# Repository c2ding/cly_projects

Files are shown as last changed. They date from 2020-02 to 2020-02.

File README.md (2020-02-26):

# 项目说明

## 结构组成
>该项目涵盖以下几个子项目：**A_CARD**、**A_Box**、**B_Card**、**C_Slot**、**Dog**。
>
>
>
>| 序号 |     名称     |       备注       |
>| :--: | :----------: | :--------------: |
>|  1   | ***A_Card*** |       卡式       |
>|  2   | ***A_Box***  | 铝制型材外壳项目 |
>|  3   | ***B_Card*** |  大尺寸电路板卡  |
>|  4   | ***C_Slot*** |  7个插槽的项目   |
>|  5   |  ***Dog***   |    看门狗项目    |

## 说明
> 1. 当前 ***仓库***  只含有 ***Dog*** 看门狗项目的PCB设计文档、说明文档等内容，最早版本是2020-01-13，今天加入了看门狗用STM32芯片的刷写方法。2020-02-26
>
> 2. 刷写器的连接方式
>
> | 线序 | 板卡上     | 白色刷写器 |          |
> | ---- | ---------- | ---------- | -------- |
> | 标识 | 七针接口   | 四针接口   | 五针接口 |
> | 1    | NET_JTMS_1 | NULL       | RST      |
> | 2    | PA9        | NULL       | NULL     |
> | 3    | PA10       | NULL       | NULL     |
> | 4    | JTMS_SWDIO | SWIO       | SWIO     |
> | 5    | GND        | GND        | GND      |
> | 6    | VCC_3.3V   | 3.3V       | 3.3V     |
> | 7    | JTMS_SWCLK | CLK        | CLK      |
>
> 3. 看门狗工作命令
>
>    ~~~c
>    "StartOn" 		//激活看门狗功能；
>    "Hearbeat" 		//心跳功能，喂狗功能；
>    "StartOff"		//关闭看门狗功能；
>    "“SW_time"		//开关间隔参数设置；
>    "HB_time"		//心跳间隔参数设置。
>    
>    ~~~
>
>    ### 增加了如何使用Keil uVision编译并刷写固件

> 1. 当前 ***仓库***  只含有 ***Dog*** 看门购项目的PCB设计文档、说明文档等内容，最早版本是2020-01-13，今天加入了看门狗用STM32芯片的刷写方法。2020-02-26

## 附属文件

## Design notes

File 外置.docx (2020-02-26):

外置“看门狗”说明

v.2020-02-26

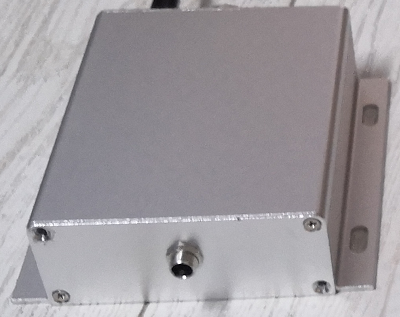
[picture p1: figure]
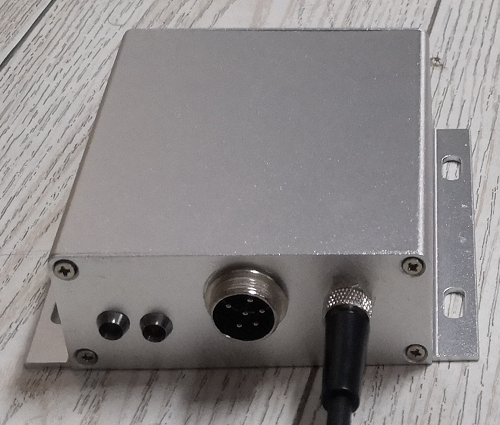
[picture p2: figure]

1、 外观

该设备由两面组成：

1. 左图：输出，由一个6芯航空母座、2.5的螺纹电源母座、两个LED指示灯组成；
2. 有图：输入，有一个2芯2.5的螺纹电源母座组成。
2、 连接方法
1. “看门狗”控制“A_Card”
A. 将12v电源适配器插入到单独一个的电源母座上，并拧紧，完成电源的输入；
B. 将黑色控制线的6芯一端接到“看门狗”另一面的6芯母座上，控制线的4芯端接到“A_Box”设备的背面；
C. “A_Box”的背板4芯母座与电路板的连接方式：
1) 电源：直接插到原来电源的位置；

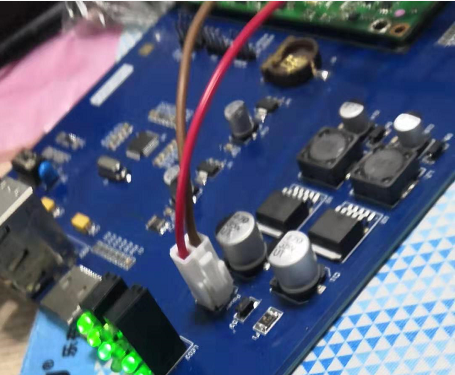
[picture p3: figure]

2) 通讯：插到电路板边角“UART”处；

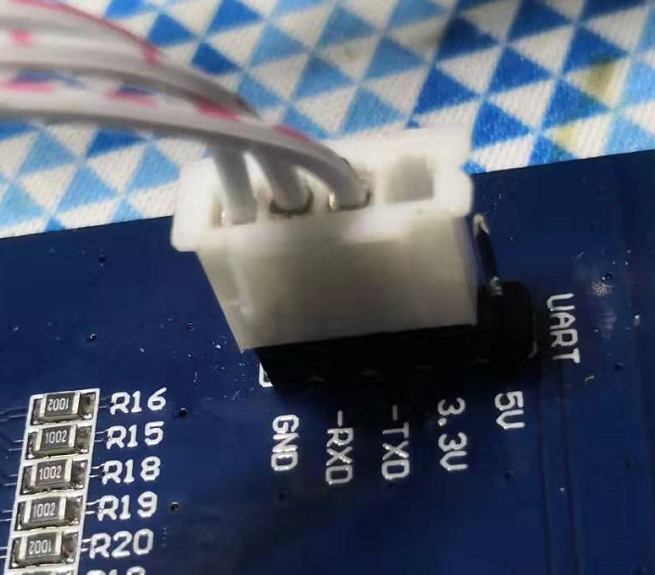
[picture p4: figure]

这是一个四针的2.45母座，其中一边为空的插入3.3V，不为空的一边插入GND，电路板5V位置空出，真的是空出一条针。

2. “看门狗”控制“RS232设备”
A. 将12v电源适配器插入到单独一个的电源母座上，并拧紧，完成电源的输入；
B. 将“浅灰色”控制线的6芯一端接到“看门狗”另一面的6芯母座上，控制线的另一端为“RS-232公头”，连接待控设备的“RS232母头”；
C. 将两端都是2.5螺纹公头电源线接入到“看门狗”电源输出母座，电源线的另一端接“待控”设备的电源接入端；

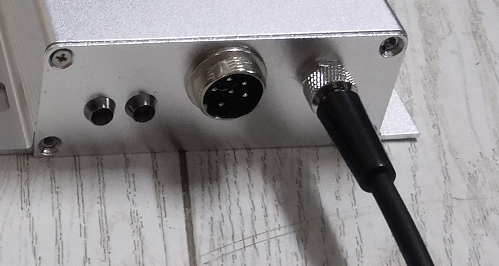
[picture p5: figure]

注：RS232的公头2、3脚采用交叉方式。

3、 线序

接“A_Box”
6芯航空头 | | | 4芯航空头
线序 | 说明 | 黑色连线 | | 线序 | 说明
1 | VCC | | | 1 | VCC
2 | Tx-RS232 | | | 2 | Rx_TTL
3 | Rx-RS232 | | | 3 | Tx_TTL
4 | Tx_TTL | | | 4 | GND
5 | Rx_TTL
6 | GND

接“待控设备”
6芯航空头 | | | RS-232 公头
线序 | 说明 | 黑色连线 | | 线序 | 说明
1 | VCC | | | 2 | Rx-RS232
2 | Tx-RS232 | | | 3 | Tx_RS232
3 | Rx-RS232 | | | 5 | GND
4 | Tx_TTL
5 | Rx_TTL
6 | GND

4、 使用方法

“StartOn”：激活看门狗功能；

“Hearbeat”：心跳功能，喂狗功能；

“StartOff”：关闭看门狗功能；

“SW_time”：开关间隔参数设置；

“HB_time”：心跳间隔参数设置。

5、 卡门狗固件刷写器连接方法
1、 找到板卡上的刷写器连接口

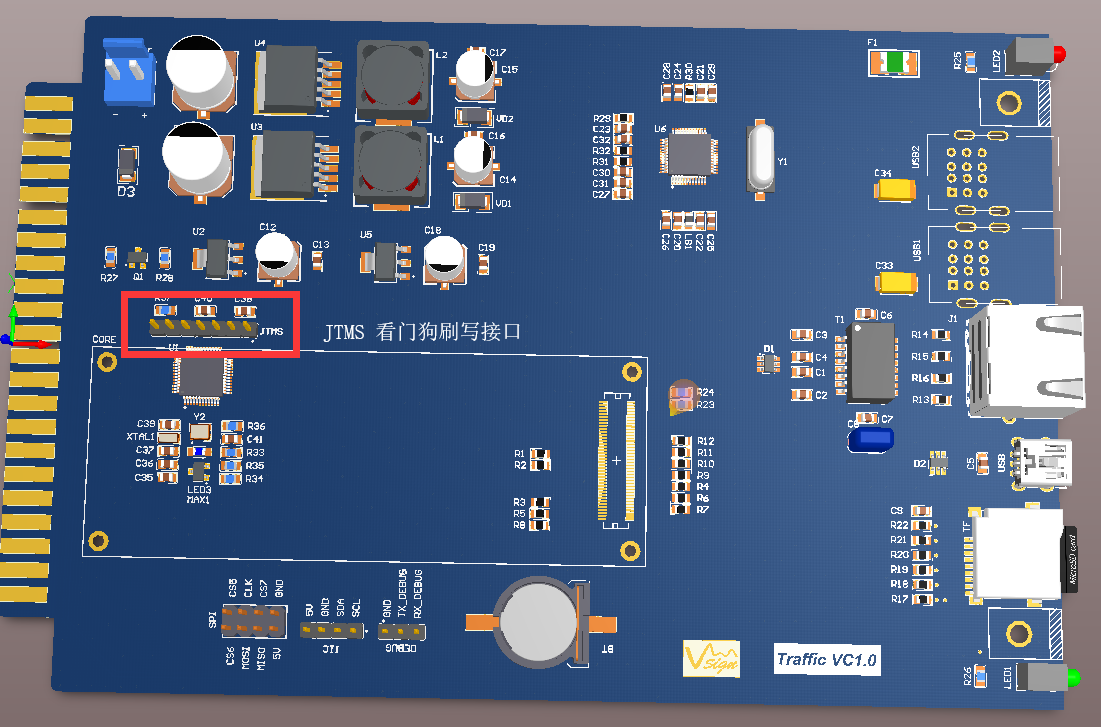
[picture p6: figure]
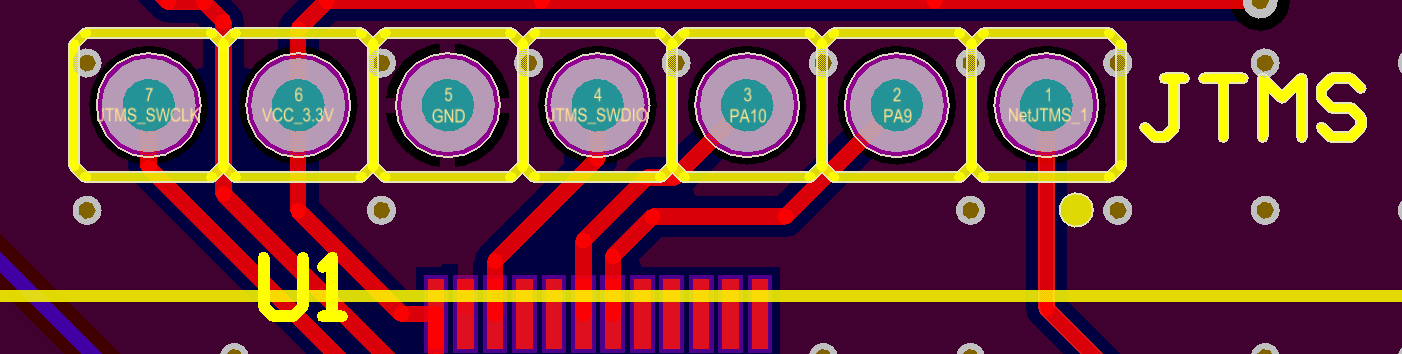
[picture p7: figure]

板卡上的JTMS标识的接口含有刷写固件功能与串口通讯功能；

2、 刷写器的接口

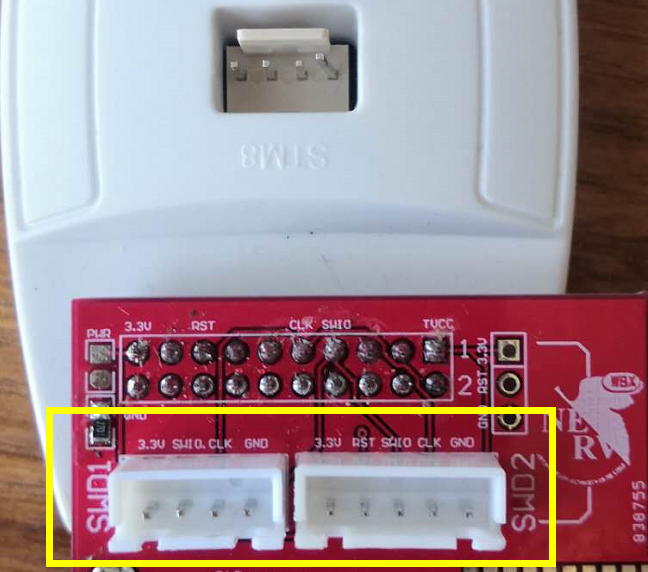
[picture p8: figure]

刷写器含有4线与5线接口，5线接口比4线接口多了一个“RST”（复位）引脚，其它引脚均为电气想通。

3、 连接方法

线序 | 板卡上的7针接口 | 白色刷写器
| 标识 | 四针接头 | 五针接头
1 | NET_JTMS_1 | NULL | RST
2 | PA9 | NULL | NULL
3 | PA10 | NULL | NULL
4 | JTMS_SWDIO | SWIO | SWIO
5 | GND | GND | GND
6 | VCC_3.3V | 3.3V | 3.3V
7 | JTMS_SWCLK | CLK | CLK

6、 刷写固件
1、 打开固件源码

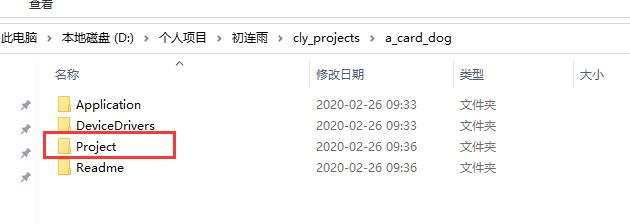
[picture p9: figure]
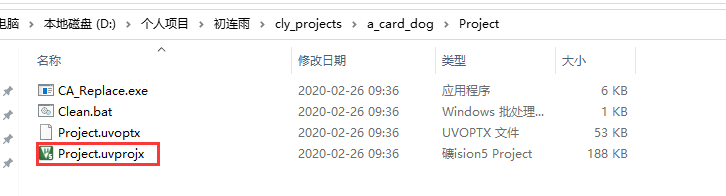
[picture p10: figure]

找到源码文件夹下的Project子目录中的Project.uvprojx文件，双击进行打开；

2、 编译源码(电机这个按钮进行编译)

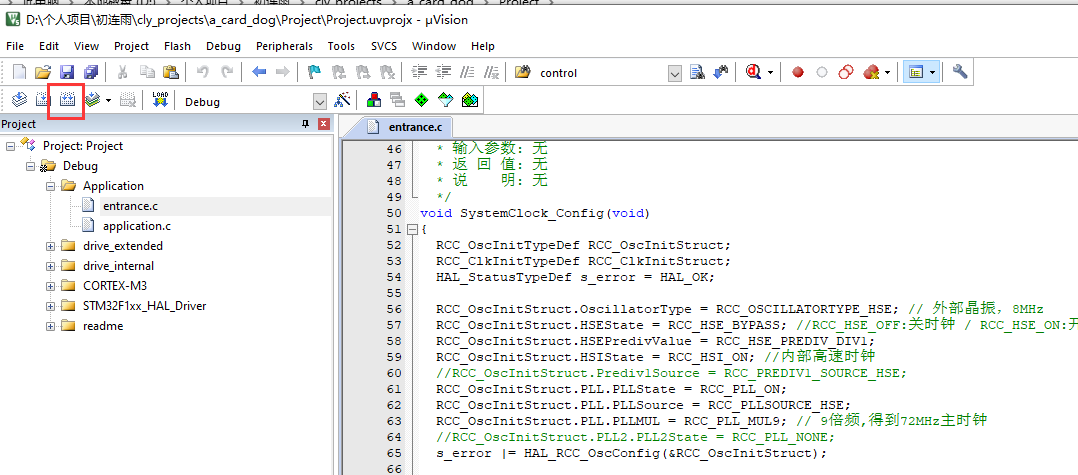
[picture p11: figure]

3、 刷写到板卡（点击如下图标）

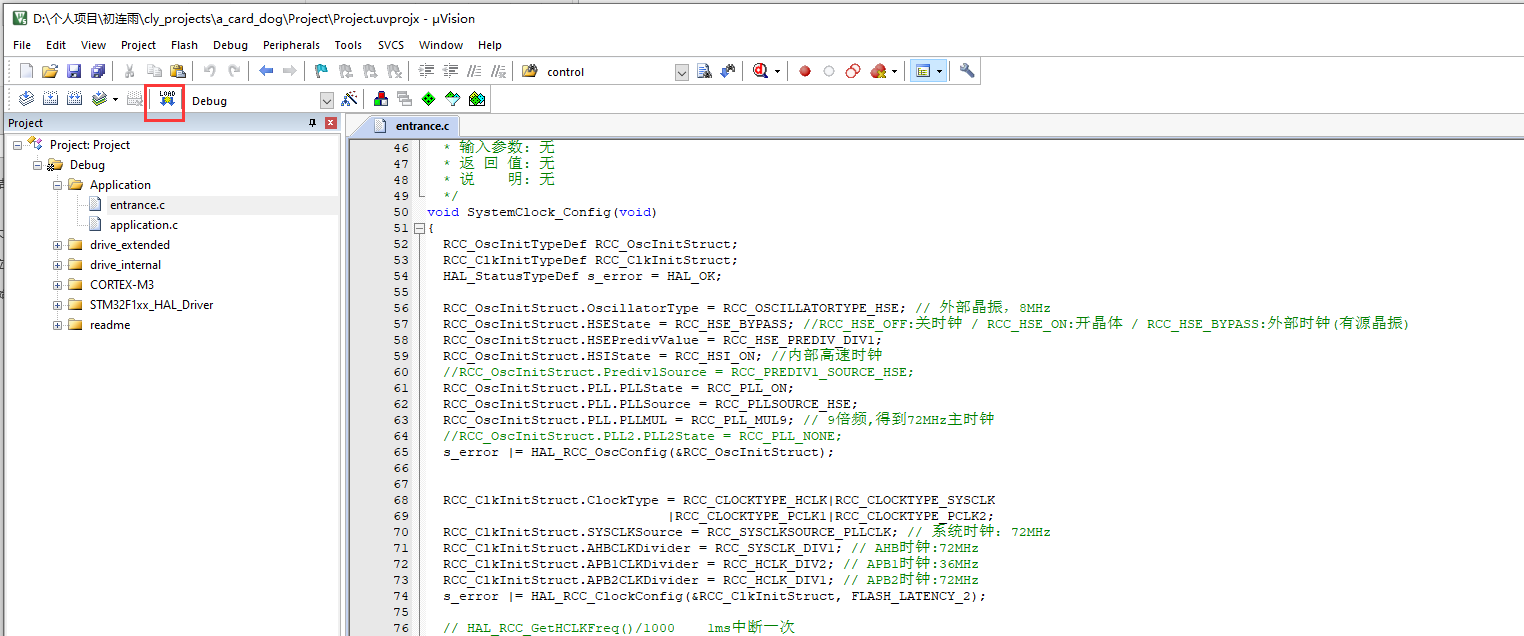
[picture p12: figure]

4、 等待软件左下角的蓝色进度条。
5、 刷写失败时查看如下是否正确
- 打开系统配置

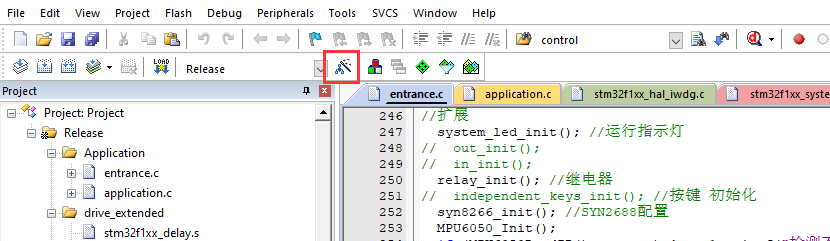
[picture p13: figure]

- 选择ST-Link Debugger，并点击右侧Settings按钮

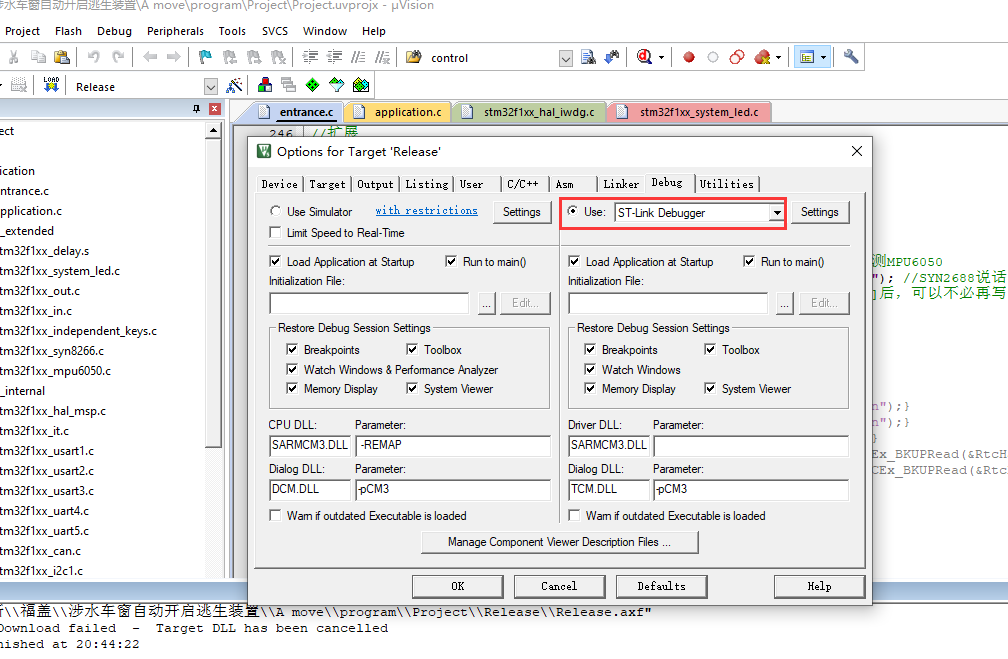
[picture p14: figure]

- 查看SW Device处是否有内容，如果没有说明连接不成功。

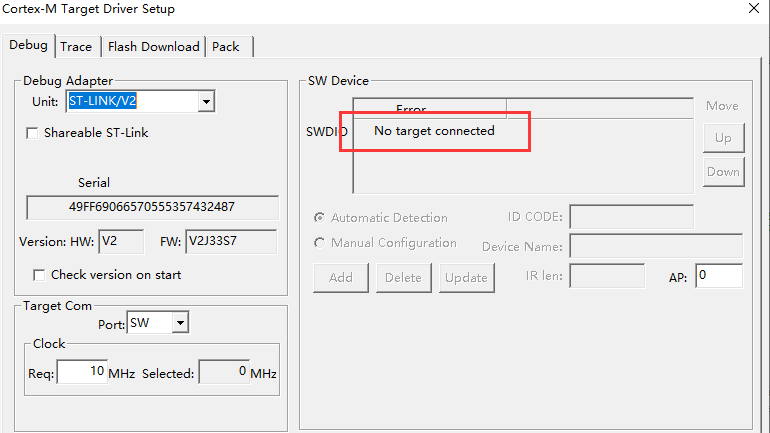
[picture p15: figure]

确保连接成功的几个条件：

1、 目标板卡需要加电；
2、 刷写器选择ST-Link Debugger;

3、确保PC的USB接口正常。

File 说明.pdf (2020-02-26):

# 外置“看门狗”说明

v.2020-02-26
一、外观

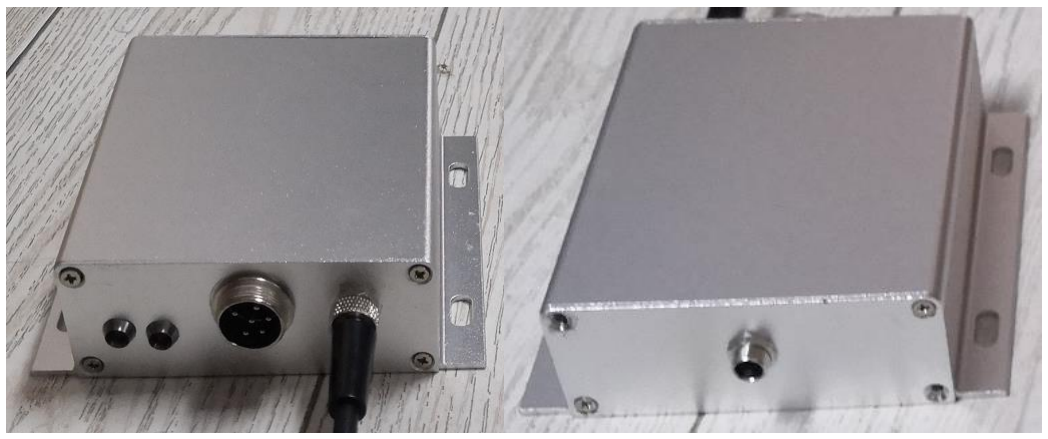
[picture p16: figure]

该设备由两面组成：
1. 左图：输出，由一个 6 芯航空母座、2.5 的螺纹电源母座、两个 LED 指示灯组 成；
2. 有图：输入，有一个 2 芯 2.5 的螺纹电源母座组成。
二、连接方法
1. “看门狗”控制“A_Card”
A. 将 12v 电源适配器插入到单独一个的电源母座上，并拧紧，完成电源的输入；
B. 将黑色控制线的 6 芯一端接到“看门狗”另一面的 6 芯母座上，控制线的 4 芯 端接到“A_Box”设备的背面；
C. “A_Box”的背板 4 芯母座与电路板的连接方式：
1) 电源：直接插到原来电源的位置；

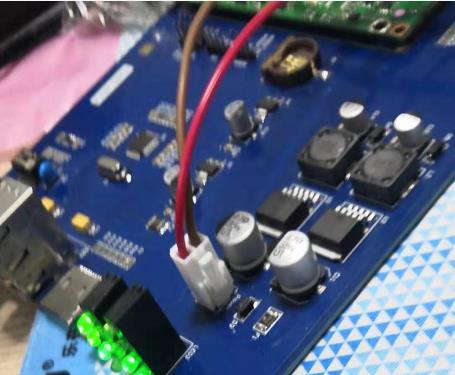
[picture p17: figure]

2) 通讯：插到电路板边角“UART”处；

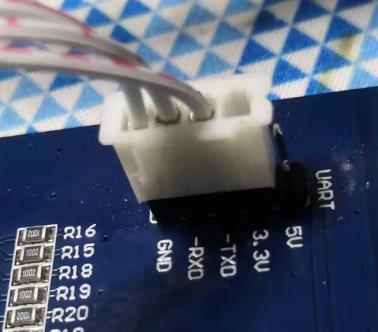
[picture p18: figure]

这是一个四针的 2.45 母座，其中一边为空的插入 3.3V，不为空的一边插 入 GND，电路板 5V 位置空出，真的是空出一条针。

2. “看门狗”控制“RS232 设备”
A. 将 12v 电源适配器插入到单独一个的电源母座上，并拧紧，完成电源的输入；
B. 将“浅灰色”控制线的 6 芯一端接到“看门狗”另一面的 6 芯母座上，控制线 的另一端为“RS-232 公头”，连接待控设备的“RS232 母头”；
C. 将两端都是 2.5 螺纹公头电源线接入到“看门狗”电源输出母座，电源线的另 一端接“待控”设备的电源接入端；

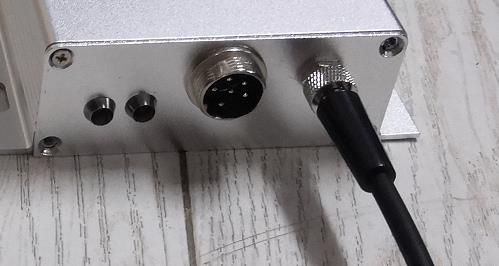
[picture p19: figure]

注：RS232 的公头 2、3 脚采用交叉方式。
三、线序
接“A_Box”
6 芯航空头 | 4 芯航空头
线序 | 说明 | 黑 色 连 线 | 线序 | 说明
1 | VCC | | 1 | VCC
2 | Tx-RS232 | | 2 | Rx_TTL
3 | Rx-RS232 | | 3 | Tx_TTL
4 | Tx_TTL | | 4 | GND
5 | Rx_TTL
6 | GND
接“待控设备”
6 芯航空头 | RS-232 公头
线序 | 说明 | 黑 色 连 线 | 线序 | 说明
1 | VCC | | 2 | Rx-RS232
2 | Tx-RS232 | | 3 | Tx_RS232
3 | Rx-RS232 | | 5 | GND
4 | Tx_TTL
5 | Rx_TTL
6 | GND

四、使用方法
“StartOn”：激活看门狗功能；
“Hearbeat”：心跳功能，喂狗功能；
“StartOff”：关闭看门狗功能；
“SW_time”：开关间隔参数设置；
“HB_time”：心跳间隔参数设置。

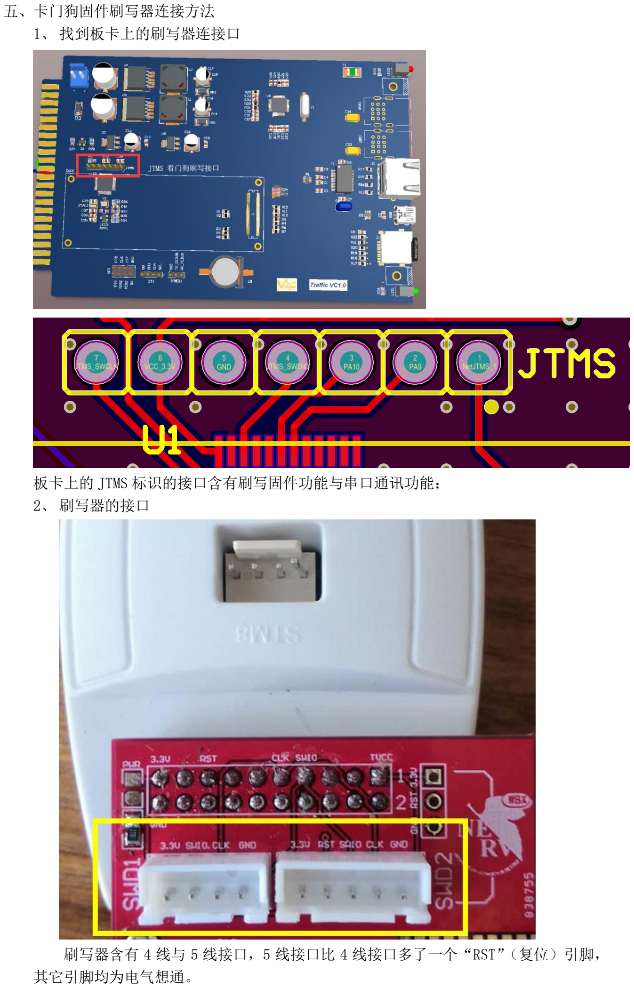
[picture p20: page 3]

五、卡门狗固件刷写器连接方法
1、 找到板卡上的刷写器连接口

板卡上的 JTMS 标识的接口含有刷写固件功能与串口通讯功能； 2、 刷写器的接口

刷写器含有 4 线与 5 线接口，5 线接口比 4 线接口多了一个“RST”（复位）引脚， 其它引脚均为电气想通。

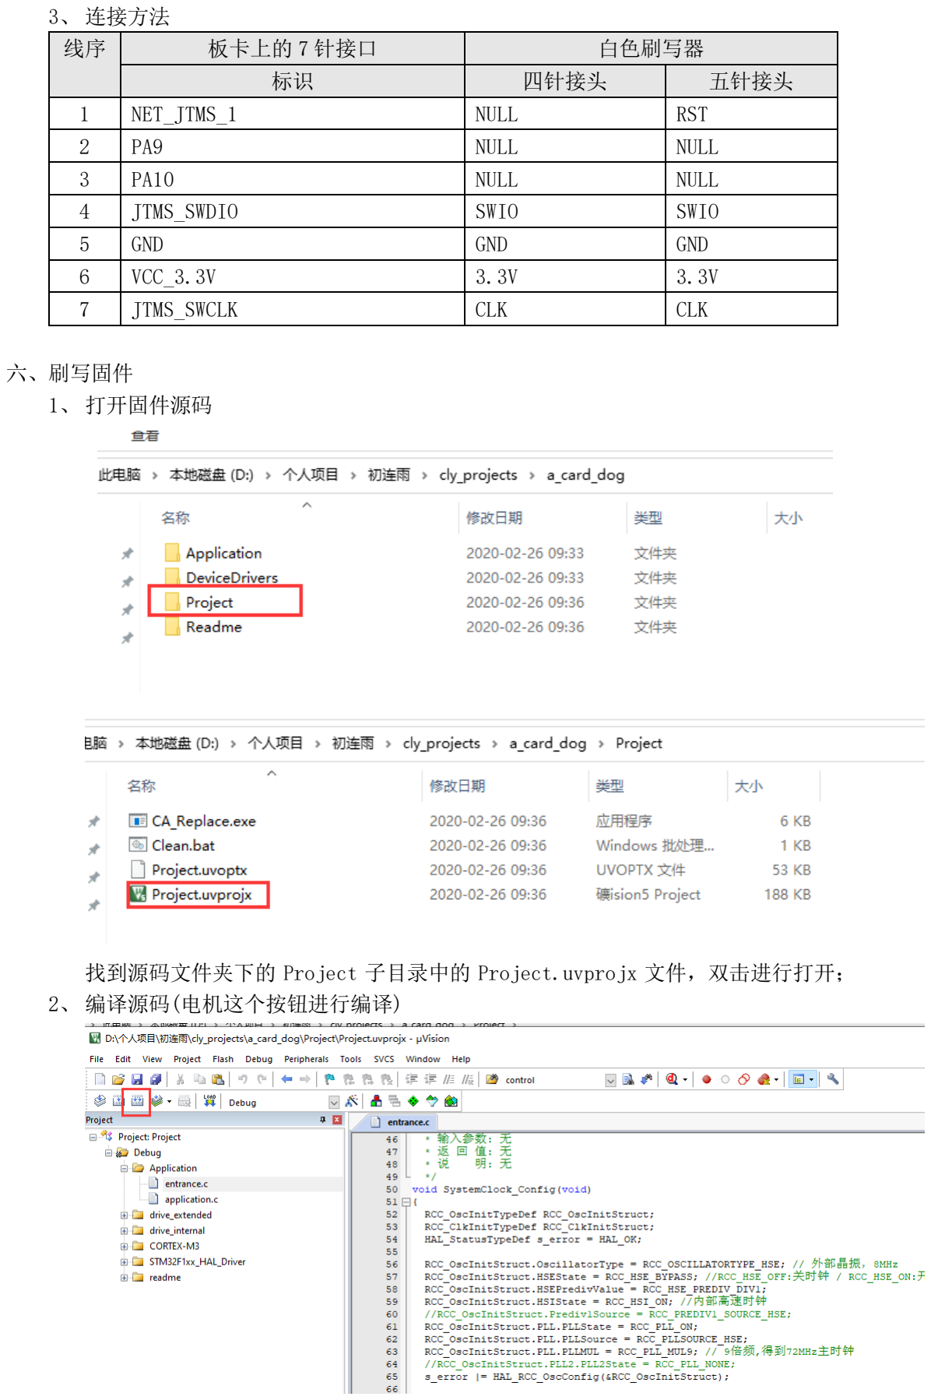
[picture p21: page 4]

3、 连接方法
线序 | 板卡上的 7 针接口 | 白色刷写器
标识 | 四针接头 | 五针接头
1 | NET_JTMS_1 | NULL | RST
2 | PA9 | NULL | NULL
3 | PA10 | NULL | NULL
4 | JTMS_SWDIO | SWIO | SWIO
5 | GND | GND | GND
6 | VCC_3.3V | 3.3V | 3.3V
7 | JTMS_SWCLK | CLK | CLK

六、刷写固件
1、 打开固件源码

找到源码文件夹下的 Project 子目录中的 Project.uvprojx 文件，双击进行打开； 2、 编译源码(电机这个按钮进行编译)

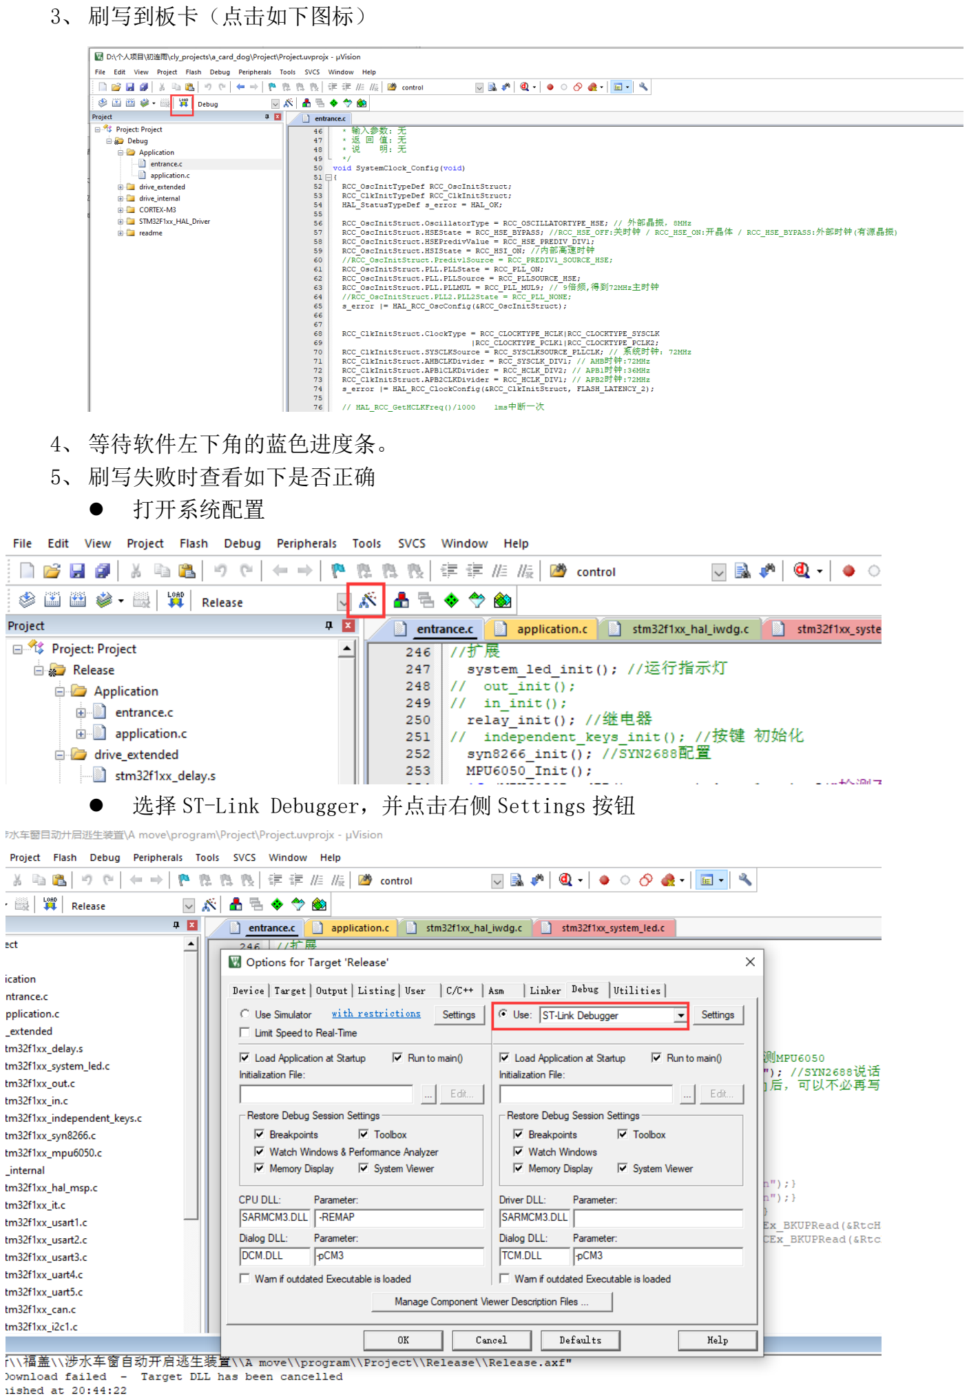
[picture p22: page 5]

3、 刷写到板卡（点击如下图标）

4、 等待软件左下角的蓝色进度条。
5、 刷写失败时查看如下是否正确
- 打开系统配置
- 选择 ST-Link Debugger，并点击右侧 Settings 按钮

- 查看 SW Device 处是否有内容，如果没有说明连接不成功。


确保连接成功的几个条件：
1、 目标板卡需要加电；
2、 刷写器选择 ST-Link Debugger; 3、确保 PC 的 USB 接口正常。

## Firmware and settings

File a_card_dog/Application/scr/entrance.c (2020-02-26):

/*

作者:刘东辉
*/
/* 包含头文件 ----------------------------------------------------------------*/
#include "stm32f1xx_usart1.h"
//#include "stm32f1xx_usart2.h"
#include "stm32f1xx_usart3.h"
//#include "stm32f1xx_uart4.h"
//#include "stm32f1xx_uart5.h"
//#include "stm32f1xx_can.h"
//#include "stm32f1xx_i2c1.h"
//#include "stm32f1xx_i2c2.h"
//#include "stm32f1xx_spi1.h"
//#include "stm32f1xx_spi2.h"
//#include "stm32f1xx_spi3.h"
//#include "stm32f1xx_tim1.h"
//#include "stm32f1xx_tim2.h"
//#include "stm32f1xx_tim3.h"
//#include "stm32f1xx_tim4.h"
//#include "stm32f1xx_tim5.h"
//#include "stm32f1xx_tim6.h"
//#include "stm32f1xx_tim7.h"
//#include "stm32f1xx_tim8.h"
//#include "stm32f1xx_flash.h"
//#include "stm32f1xx_adc1.h"
//#include "stm32f1xx_adc2.h"
//#include "stm32f1xx_adc3.h"

#include "stm32f1xx_delay.h"
#include "stm32f1xx_system_led.h"

#include "entrance.h"
#include "application.h"
/* 私有类型定义 --------------------------------------------------------------*/
/* 私有宏定义 ----------------------------------------------------------------*/
/* 私有变量 ------------------------------------------------------------------*/
/* 扩展变量 ------------------------------------------------------------------*/
__IO _SYSTEM_STATUS g_system;

RTC_HandleTypeDef RtcHandle;
/* 私有函数原形 --------------------------------------------------------------*/
/* 函数体 --------------------------------------------------------------------*/
/**
  * 函数功能: 系统时钟配置
  * 输入参数: 无
  * 返 回 值: 无
  * 说    明: 无
  */
void SystemClock_Config(void)
{
	RCC_OscInitTypeDef RCC_OscInitStruct;
	RCC_ClkInitTypeDef RCC_ClkInitStruct;
	HAL_StatusTypeDef s_error = HAL_OK;

	RCC_OscInitStruct.OscillatorType = RCC_OSCILLATORTYPE_HSE; // 外部晶振，8MHz
	RCC_OscInitStruct.HSEState = RCC_HSE_BYPASS; //RCC_HSE_OFF:关时钟 / RCC_HSE_ON:开晶体 / RCC_HSE_BYPASS:外部时钟(有源晶振)
	RCC_OscInitStruct.HSEPredivValue = RCC_HSE_PREDIV_DIV1;
	RCC_OscInitStruct.HSIState = RCC_HSI_ON; //内部高速时钟
	//RCC_OscInitStruct.Prediv1Source = RCC_PREDIV1_SOURCE_HSE;
	RCC_OscInitStruct.PLL.PLLState = RCC_PLL_ON;
	RCC_OscInitStruct.PLL.PLLSource = RCC_PLLSOURCE_HSE;
	RCC_OscInitStruct.PLL.PLLMUL = RCC_PLL_MUL9; // 9倍频,得到72MHz主时钟
	//RCC_OscInitStruct.PLL2.PLL2State = RCC_PLL_NONE;
	s_error |= HAL_RCC_OscConfig(&RCC_OscInitStruct);


	RCC_ClkInitStruct.ClockType = RCC_CLOCKTYPE_HCLK|RCC_CLOCKTYPE_SYSCLK
                              |RCC_CLOCKTYPE_PCLK1|RCC_CLOCKTYPE_PCLK2;
	RCC_ClkInitStruct.SYSCLKSource = RCC_SYSCLKSOURCE_PLLCLK; // 系统时钟：72MHz
	RCC_ClkInitStruct.AHBCLKDivider = RCC_SYSCLK_DIV1; // AHB时钟:72MHz
	RCC_ClkInitStruct.APB1CLKDivider = RCC_HCLK_DIV2; // APB1时钟:36MHz
	RCC_ClkInitStruct.APB2CLKDivider = RCC_HCLK_DIV1; // APB2时钟:72MHz
	s_error |= HAL_RCC_ClockConfig(&RCC_ClkInitStruct, FLASH_LATENCY_2);

 	// HAL_RCC_GetHCLKFreq()/1000    1ms中断一次
	// HAL_RCC_GetHCLKFreq()/100000	 10us中断一次
	// HAL_RCC_GetHCLKFreq()/1000000 1us中断一次
	HAL_SYSTICK_Config(HAL_RCC_GetHCLKFreq()/1000/8);  // 配置并启动系统滴答定时器
	/* 系统滴答定时器时钟源 */
	HAL_SYSTICK_CLKSourceConfig(SYSTICK_CLKSOURCE_HCLK_DIV8);
	/* 系统滴答定时器中断优先级配置 */
	HAL_NVIC_SetPriority(SysTick_IRQn, 0, 0);

	if (s_error != HAL_OK)
	{
		Soft_Reset(); // 复位
	}
}
/*----------------------------------------------------------------------------*/
/**
  * 函数功能: 独立看门狗初始化配置
  * 溢出时间(毫秒) = hiwdg.Init.Prescaler/40 * hiwdg.Init.Reload 
  * hiwdg.Init.Prescaler : (4,8,16,32,64,128,256)
  * hiwdg.Init.Reload < 0xFFF
  */
IWDG_HandleTypeDef hiwdg;
void IWDG_Configuration(void) //看门狗配置
{
	HAL_StatusTypeDef s_error = HAL_OK;
	hiwdg.Instance = IWDG;
	hiwdg.Init.Prescaler = IWDG_PRESCALER_256; //时钟分频
	hiwdg.Init.Reload = 0x0FFF; //计数
	s_error |= HAL_IWDG_Init(&hiwdg); //初始化看门狗

#ifdef USE_FULL_ASSERT
	if (s_error == HAL_OK)
	{
		printf("IWDG_Configuration(); OK\r\n"); 
	} else
	{
		printf("IWDG_Configuration(); ERROR\r\n"); 
	}
#endif
}
/*----------------------------------------------------------------------------*/
//初始化
void initialization(void)
{
	HAL_Init(); // 复位所有外设，初始化Flash接口和系统滴答定时器
	SystemClock_Config(); // 配置系统时钟
	
	__HAL_AFIO_REMAP_PD01_ENABLE(); //PD1做IO口用
//端口
#ifdef __HAL_RCC_GPIOA_CLK_ENABLE
	__HAL_RCC_GPIOA_CLK_ENABLE();
#endif
#ifdef __HAL_RCC_GPIOB_CLK_ENABLE
	__HAL_RCC_GPIOB_CLK_ENABLE();
#endif
#ifdef __HAL_RCC_GPIOC_CLK_ENABLE
	__HAL_RCC_GPIOC_CLK_ENABLE();
#endif
#ifdef __HAL_RCC_GPIOD_CLK_ENABLE
	__HAL_RCC_GPIOD_CLK_ENABLE();
#endif
#ifdef __HAL_RCC_GPIOE_CLK_ENABLE
	__HAL_RCC_GPIOE_CLK_ENABLE();
#endif
#ifdef __HAL_RCC_GPIOF_CLK_ENABLE
	__HAL_RCC_GPIOF_CLK_ENABLE();
#endif
#ifdef __HAL_RCC_GPIOG_CLK_ENABLE
	__HAL_RCC_GPIOG_CLK_ENABLE();
#endif
#ifdef __HAL_RCC_GPIOH_CLK_ENABLE
	__HAL_RCC_GPIOH_CLK_ENABLE();
#endif
#ifdef __HAL_RCC_GPIOI_CLK_ENABLE
	__HAL_RCC_GPIOI_CLK_ENABLE();
#endif
#ifdef __HAL_RCC_GPIOJ_CLK_ENABLE
	__HAL_RCC_GPIOJ_CLK_ENABLE();
#endif
#ifdef __HAL_RCC_GPIOK_CLK_ENABLE
	__HAL_RCC_GPIOK_CLK_ENABLE();
#endif
	
//外设
//调试用 放在第一个启动
#ifdef __STM32F1XX_USART1_H__
	MX_USART1_Init();
#endif
#ifdef __STM32F1XX_USART2_H__
	MX_USART2_Init();
#endif
#ifdef __STM32F1XX_USART3_H__
	MX_USART3_Init();
#endif
#ifdef __STM32F1XX_UART4_H__
	MX_UART4_Init();
#endif
#ifdef __STM32F1XX_UART5_H__
	MX_UART5_Init();
#endif
#ifdef __STM32F1XX_CAN_H__
	MX_CAN1_Init(CAN_BAND_125);
#ifdef USE_CAN2
	MX_CAN2_Init(CAN_BAND_125);
#endif
#endif
#ifdef __STM32F1XX_I2C1_H__
	MX_I2C1_Init();
#endif
#ifdef __STM32F1XX_I2C2_H__
	MX_I2C2_Init();
#endif
#ifdef __STM32F1XX_SPI1_H__
	MX_SPI1_Init();
#endif
#ifdef __STM32F1XX_SPI2_H__
	MX_SPI2_Init();
#endif
#ifdef __STM32F1XX_SPI3_H__
	MX_SPI3_Init();
#endif
#ifdef __STM32F1XX_TIM1_H__
	MX_TIM1_Init();
#endif
#ifdef __STM32F1XX_TIM2_H__
	MX_TIM2_Init();
#endif
#ifdef __STM32F1XX_TIM3_H__
	MX_TIM3_Init();
#endif
#ifdef __STM32F1XX_TIM4_H__
	MX_TIM4_Init();
#endif
#ifdef __STM32F1XX_TIM5_H__
	MX_TIM5_Init();
#endif
#ifdef __STM32F1XX_TIM6_H__
	MX_TIM6_Init();
#endif
#ifdef __STM32F1XX_TIM7_H__
	MX_TIM7_Init();
#endif
#ifdef __STM32F1XX_TIM8_H__
	MX_TIM8_Init();
#endif
#ifdef __STM32F1XX_ADC1_H__
	MX_ADC1_Init();
#endif
#ifdef __STM32F1XX_ADC2_H__
	MX_ADC2_Init();
#endif
#ifdef __STM32F1XX_ADC3_H__
	MX_ADC3_Init();
#endif
//	IWDG_Configuration();

//扩展
	system_led_init(); //运行指示灯
	power_out_init();

//数据

#if 0
	//if (__HAL_RCC_GET_FLAG(RCC_FLAG_PINRST)) {printf("引脚复位\r\n");} 
	if (__HAL_RCC_GET_FLAG(RCC_FLAG_PORRST)) {printf("上电复位\r\n");} 
	if (__HAL_RCC_GET_FLAG(RCC_FLAG_SFTRST)) {printf("软件复位\r\n");} 
	if (__HAL_RCC_GET_FLAG(RCC_FLAG_IWDGRST)) {printf("独立看门狗复位\r\n");} 
	if (__HAL_RCC_GET_FLAG(RCC_FLAG_WWDGRST)) {printf("窗口看门狗复位\r\n");} 
	if (__HAL_RCC_GET_FLAG(RCC_FLAG_LPWRRST)) {printf("低电量复位\r\n");} 
	if (__HAL_RCC_GET_FLAG(RCC_FLAG_SFTRST)) {g_datum.switcher = HAL_RTCEx_BKUPRead(&RtcHandle, RTC_BKP_DR1);} //软件复位
	if (__HAL_RCC_GET_FLAG(RCC_FLAG_IWDGRST)) {g_datum.switcher = HAL_RTCEx_BKUPRead(&RtcHandle, RTC_BKP_DR1);} //独立看门狗复位
	__HAL_RCC_CLEAR_RESET_FLAGS(); //清除复位源标志位
#endif
//运行模式选择

	memset((uint8_t*)&work, 0x00, sizeof(work));

	g_system.event.whole = 0; //任务 事件
//	g_system.button_datum = 0; //按键 数据
	g_system.working_state = STANBDY; //工作状态 待机
	g_system.time_SysTick = 0;

#ifdef USE_FULL_ASSERT
	//printf("初始化完成 按空格键 继续\r\n");
	//while (getchar()!=' ') {;}
	printf("Initialization complete\r\n");
#endif
	IWDG_Configuration();
	//__enable_irq(); // 开启总中断
}
/*----------------------------------------------------------------------------*/
const uint8_t git_power[]={"0123456789"};
//运行
void function(void)
{

	for (;;)
	{
		if (second_event != NULL) //秒
		{
			HAL_IWDG_Refresh(&hiwdg); //喂狗
			control();
			second_event = NULL;
		}
		else if (millisecond_event != NULL) //100mS
		{
			system_led();
			millisecond_event = NULL;
		}
		#ifdef __STM32F1XX_USART3_H__
		else if (usart3_event != NULL) //usart3 (GPRS接收数据处理)
		{
			uint32_t s_length;
			s_length = MX_USART3_input((uint8_t *)&*work.in_buffer, 255), work.in_buffer[s_length] = '\0';
			data_collection();
			
			//MX_USART3_output((uint8_t *)&*sim7600_rx_buffer);
			usart3_event = NULL;
		}
		#endif
		//else {while (whole_event == NULL) {HAL_PWR_EnterSLEEPMode(PWR_MAINREGULATOR_ON, PWR_SLEEPENTRY_WFI);}} //再次烧写会出问题
		else {whole_event = NULL; while (whole_event == NULL) {;}} //调试时用
	}
}
/*----------------------------------------------------------------------------*/
int main(void) {initialization(); function(); return 0;}
/*----------------------------------------------------------------------------*/
/**
  *	用户可以选择是否使能HAL库的断言供能。使能断言的方法有两种：
  * (1) 在C编译器的预定义宏选项中定义USE_FULL_ASSERT。
  *	(2) 在stm32f1xx_hal_conf.h文件取消"#define USE_FULL_ASSERT    1"行的注释。	
  * 函数功能: 断言失败服务函数
  * 输入参数: file : 源代码文件名称。关键字__FILE__表示源代码文件名。
  *           line ：代码行号。关键字 __LINE__ 表示源代码行号
  */
#ifdef USE_FULL_ASSERT
void assert_failed(uint8_t* file, uint32_t line)
{ 
	printf("\r\nWrong parameters value: file %s on line %d\r\n", file, line);
	//printf("\n\r Wrong parameter value detected on\r\n");
	//printf("       file  %s\r\n", file);
	//printf("       line  %d\r\n", line);
	for (;;) {;}
}
#endif
/*----------------------------------------------------------------------------*/
/**
  * 函数功能: 系统软件复位
  */
void Soft_Reset(void)
{
	__disable_irq(); // 关闭总中断
	NVIC_SystemReset(); // 系统复位
}
/*----------------------------------------------------------------------------*/

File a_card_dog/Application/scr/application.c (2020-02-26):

/*

作者:刘东辉
*/
/* 包含头文件 ----------------------------------------------------------------*/
#ifdef USE_FULL_ASSERT
//#include "stm32f1xx_usart1.h"
#endif
#include "stm32f1xx_delay.h"
//#include "stm32f1xx_delay.h"
//#include "stm32f1xx_time1.h"
#include "stm32f1xx_usart3.h"
//#include "stm32f1xx_uart4.h"
//#include "stm32f1xx_uart5.h"
#include "stm32f1xx_flash.h"

#include "port_bit.h"
#include "stm32f1xx_system_led.h"
//#include "stm32f1xx_led.h"

#include "entrance.h"
#include "application.h"
/* 私有宏定义 ----------------------------------------------------------------*/
#define power_out_port			GPIOB
#define power_out_pin			GPIO_PIN_4
#define POWER_OUT_OFF()			HAL_GPIO_WritePin(power_out_port, power_out_pin, GPIO_PIN_RESET)
#define POWER_OUT_ON()			HAL_GPIO_WritePin(power_out_port, power_out_pin, GPIO_PIN_SET)
/* 私有类型定义 --------------------------------------------------------------*/
/* 私有变量 ------------------------------------------------------------------*/
/* 扩展变量 ------------------------------------------------------------------*/
_WORK work;
const _PARAMETER parameter __attribute__((at(OFFSER_BUFFER_FLASH_ADDRESS))) = {
	.start_wait = 480, //启动等待
	.heartbeat = 60, //心跳
};
/* 私有函数原形 --------------------------------------------------------------*/
/* 函数体 --------------------------------------------------------------------*/

void data_collection(void) //采集数据
{
	char *str;
	_PARAMETER s_parameter;

	str = strstr((char*)&work.in_buffer, "Heartbeat"); //心跳
	if (str != NULL)
	{
		work.time = 0;
		u3_printf("%d %d\n", work.er_h, work.er_s);
		printf("Heartbeat\r\n");
	}
	str = strstr((char*)&work.in_buffer, "StartOn"); //监控启动
	if (str != NULL)
	{
		work.start = true;
		work.time = 0;
		g_system.working_state = FUNCTION; //工作状态 待机
		printf("StartOn\r\n");
	}
	str = strstr((char*)&work.in_buffer, "StartOff"); //监控停止
	if (str != NULL)
	{
		work.start = false;
		work.time = 0xFFFFFFFF;
		g_system.working_state = STANBDY; //工作状态 待机
		printf("StartOff\r\n");
	}
	str = strstr((char*)&work.in_buffer, "SW_time:"); //参数设置
	if (str != NULL)
	{
		HAL_FLASH_Read(OFFSER_BUFFER_FLASH_ADDRESS, (uint16_t *)&s_parameter, sizeof(s_parameter)/2);
		s_parameter.start_wait = atoi(str + strlen("SW_time:"));
		HAL_FLASH_Write(OFFSER_BUFFER_FLASH_ADDRESS, (uint16_t *)&s_parameter, sizeof(s_parameter)/2);
		printf("SW_time:%d\r\n", parameter.start_wait);
	}
	str = strstr((char*)&work.in_buffer, "HB_time:"); //参数设置
	if (str != NULL)
	{
		HAL_FLASH_Read(OFFSER_BUFFER_FLASH_ADDRESS, (uint16_t *)&s_parameter, sizeof(s_parameter)/2);
		s_parameter.heartbeat = atoi(str + strlen("HB_time:"));
		HAL_FLASH_Write(OFFSER_BUFFER_FLASH_ADDRESS, (uint16_t *)&s_parameter, sizeof(s_parameter)/2);
		printf("HB_time:%d\r\n", parameter.heartbeat);
	}
}
/*----------------------------------------------------------------------------*/
void control(void) //控制
{
	if (work.start == false) //等待开机
	{
		if (work.time==parameter.start_wait) {POWER_OUT_OFF();}
		if (work.time==parameter.start_wait+1) {POWER_OUT_ON();}
		if (work.time==parameter.start_wait+2) {work.start = false, work.time = 0, work.er_s++, printf("er_h:%d; er_s:%d\r\n", work.er_h, work.er_s);}
	} else //启动心跳
	{
		if (work.time==parameter.heartbeat) {POWER_OUT_OFF();}
		if (work.time==parameter.heartbeat+1) {POWER_OUT_ON();}
		if (work.time==parameter.heartbeat+2) {work.start = false, work.time = 0, work.er_h++, g_system.working_state = STANBDY, printf("er_h:%d; er_s:%d\r\n", work.er_h, work.er_s);}
	}
	if (work.time < 0xFFFFFFFF) {work.time++;}
}
/*----------------------------------------------------------------------------*/
void power_out_init(void) //
{
	GPIO_InitTypeDef GPIO_InitStruct; 

	GPIO_InitStruct.Pin = power_out_pin;
	GPIO_InitStruct.Mode = GPIO_MODE_OUTPUT_PP;
	GPIO_InitStruct.Speed = GPIO_SPEED_FREQ_HIGH;
	HAL_GPIO_Init(power_out_port, &GPIO_InitStruct);
	HAL_GPIO_LockPin(power_out_port, power_out_pin); //锁定配置
	POWER_OUT_ON();
}
/*----------------------------------------------------------------------------*/
void u3_printf(const char *fmt, ...) //发送数据
{
    va_list ap;
    char string[128];
	uint32_t length;

	va_start(ap, fmt);
	length = vsprintf(string, fmt, ap);
	va_end(ap);
	
	MX_USART3_output((uint8_t*)&string, length);
}
/*----------------------------------------------------------------------------*/

/*----------------------------------------------------------------------------*/

/*----------------------------------------------------------------------------*/

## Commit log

2020-02-26 修改文件
2020-02-26 update
    当前 仓库 只含有 Dog 看门购项目的PCB设计文档、说明文档等内容，最早版本是2020-01-13，今天加入了看门狗用STM32芯片的刷写方法。2020-02-26
2020-02-26 修改一些问题
2020-02-26 更新了说明文档
2020-03-02 3月更新
